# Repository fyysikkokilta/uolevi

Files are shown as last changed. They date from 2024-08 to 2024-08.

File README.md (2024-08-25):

# Uolevi

How to use Uolevi:
1. To PLAY a song, you can press the reset button in Uolevi's arm.
2. To STOP a song, you can hold the mode switch closer to the shoulder of the same arm until the eye LEDs turn on.
3. To CHANGE the song, you can keep holding the mode switch until the LEDs turn off, after which the number of beeps will indicate which song is selected. To select the next song, you can repeat this process. If the song selection is not indicated, you can retry changing the song, or reset Uolevi and retry. When you hear the correct number of beeps, you need to wait until the song is copied onto onboard memory and Uolevi plays the song. The eye LEDs indicate a loading is in progress. At most the loading time is approximately 6 minutes for the longest duration of song programmable (9 min 21 s).
4. To ADD new songs, you can take out the micro SD card in Uolevi's back, to the left of the battery compartment, and follow the programming instructions in the "Programming" directory.
---

Project documentation is split into the following directory structure:
- 3D Models: 3D-printable mechanical components
- Electronics: Schematics and bill of materials for PCB design
- Firmware: Code for microcontroller firmware
- Programming: Software and instructions for programming new songs onto Uolevi

Estimated current draw of Uolevi Rev 1.1 for functionalities and modes of operation at 4.5 V:
- Mouth motor: 0.9 A
- Legs motor: 0.4 A
- Eye LEDs: 2 x 20 mA
- Speaker: 40 mA
- Loading song from SD card onto external flash: 40 mA
- Standby mode (software power off): 4 mA
- Power off (timer chip 3.3 V cutoff): 50 nA

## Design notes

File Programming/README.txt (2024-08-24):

To program a song to Uolevi, open the "Songs" directory and create a file called "<song_name>.txt". Copy the .wav song file to be programmed to the same directory.

Different programming parameters are separated by lines, and data values are separated by spaces. The first line should contain the song file name. The next 4 lines should contain toggle times in seconds for the leg motor, mouth motor, left eye LED, and right eye LED, respectively.

Run the programmer.py script in the "Python" directory and input the "<song_name>.txt" file name for programming. Finally copy the created "<song_name>.ulv" to the root directory of the SD card and rename to indicate order ("<0-9>.ulv") in songs to load to Uolevi.
A song is loaded into active memory by inserting the SD card into Uolevi and holding Uolevi's upper left hand button down until the eye LEDs have turned on and off. This can be repeated to select the desired song, indicated by the number of beeps (1-10). Wait until the song starts playing to make sure loading is finished.

Below is an example of a programming file.
---
example.wav
0.0 1.0 5.0 5.1
0.01 0.012 0.053 0.1 2.0 2.1

1.0 4.8 5.25

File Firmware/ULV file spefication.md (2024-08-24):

# ULV File specification

ULV 1.0
- The ULV 1.0 file specification begins with a 4-byte header consisting of a 32-bit unsigned integer N, encoded as little endian. The header is then followed by N data bytes.
- The first data byte contains the first 2 "mechanical" samples with the following bit assignment: 0 (LSB) - leg motors 1st sample, 1 - mouth motor 1st sample, 2 - left eye LED 1st sample, 3 - right eye LED 1st sample, 4 - leg 2nd sample, 5 - mouth 2nd sample, 6 - left eye 2nd sample, 7 (MSB) - right eye 2nd sample.
- The next 1492 data bytes contain the first 1492 audio samples encoded as 8-bit unsigned integers. These are then followed by the next mechanical sample byte and the next 1492 data bytes, and so on, until the end of the file.

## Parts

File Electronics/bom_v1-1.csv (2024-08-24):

Reference | Value | Footprint | Qty
C1 | 100u | C_Radial_D5.0mm_H11.0mm_P2.00mm | 1
C2,C4,C7 | 1u | C_0603 | 3
C3,C6,C8,C9,C10 | 0.1u | C_0603 | 5
C5 | 0.47u | C_0603 | 1
D4 | 1N5822 | D_DO-201AD_P15.24mm_Horizontal | 1
J1 | MSD-1-A | MSD-1-A | 1
J8 | Header_UPDI | PinHeader_2x03_P2.54mm_Vertical | 1
Q1,Q2 | D882 | SOT-89-3 | 2
Q3 | BC856 | SOT-23-3 | 1
R1,R3 | 20k | R_0603 | 2
R2,R4 | 49.9 | R_0603 | 2
R5,R6,R9 | 200 | R_0603 | 3
R7 | 1M | R_0603 | 1
R8,R10 | 100k | R_0603 | 2
R11 | 47k | R_0603 | 1
U1 | ATtiny1614-SS | 14-SOIC | 1
U2 | W25Q128JVS | 8-SOIC | 1
U3 | MIC5504-3.3YM5 | SOT-23-5 | 1
U4 | TPL5110DDCTQ1 | SOT-23-6 | 1
U5 | IS31AP4991-SLS2 | 8-MSOP | 1

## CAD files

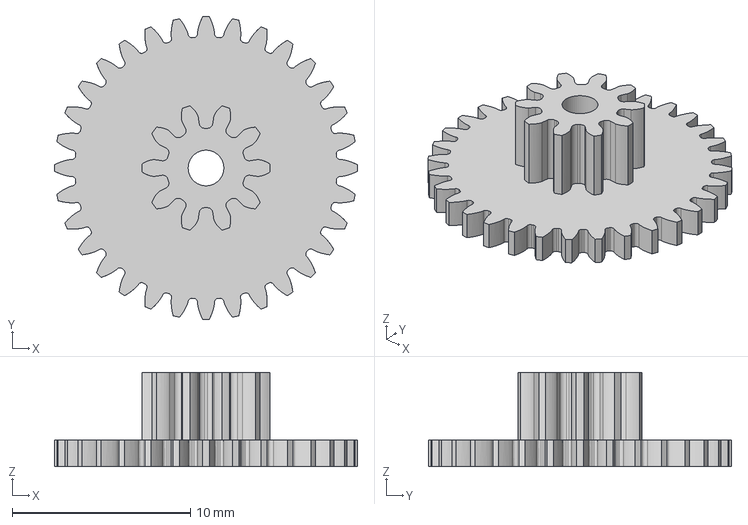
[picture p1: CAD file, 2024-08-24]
3D Models/gear_0_v1.step
17.0 x 17.0 x 5.30 mm
Spur Gear (32 teeth) (2)
Spur Gear (10 teeth)

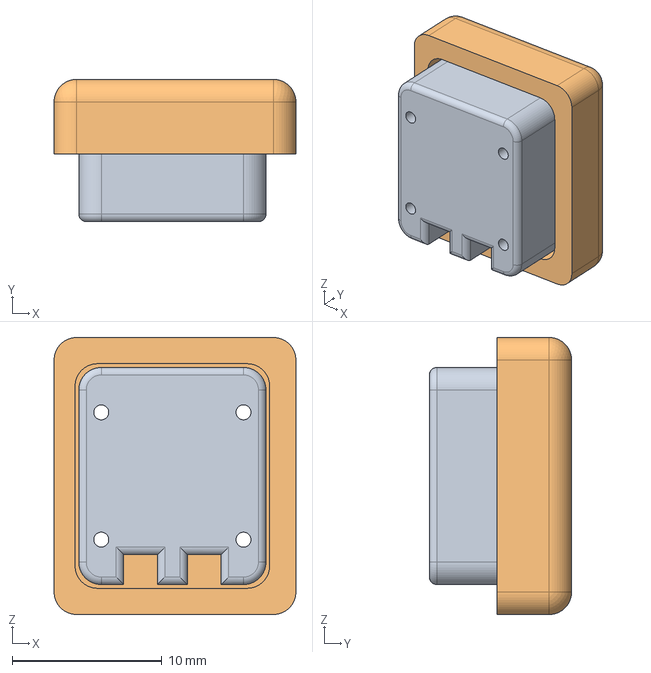
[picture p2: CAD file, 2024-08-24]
3D Models/switch_case_v1.step
16.1 x 9.50 x 18.5 mm

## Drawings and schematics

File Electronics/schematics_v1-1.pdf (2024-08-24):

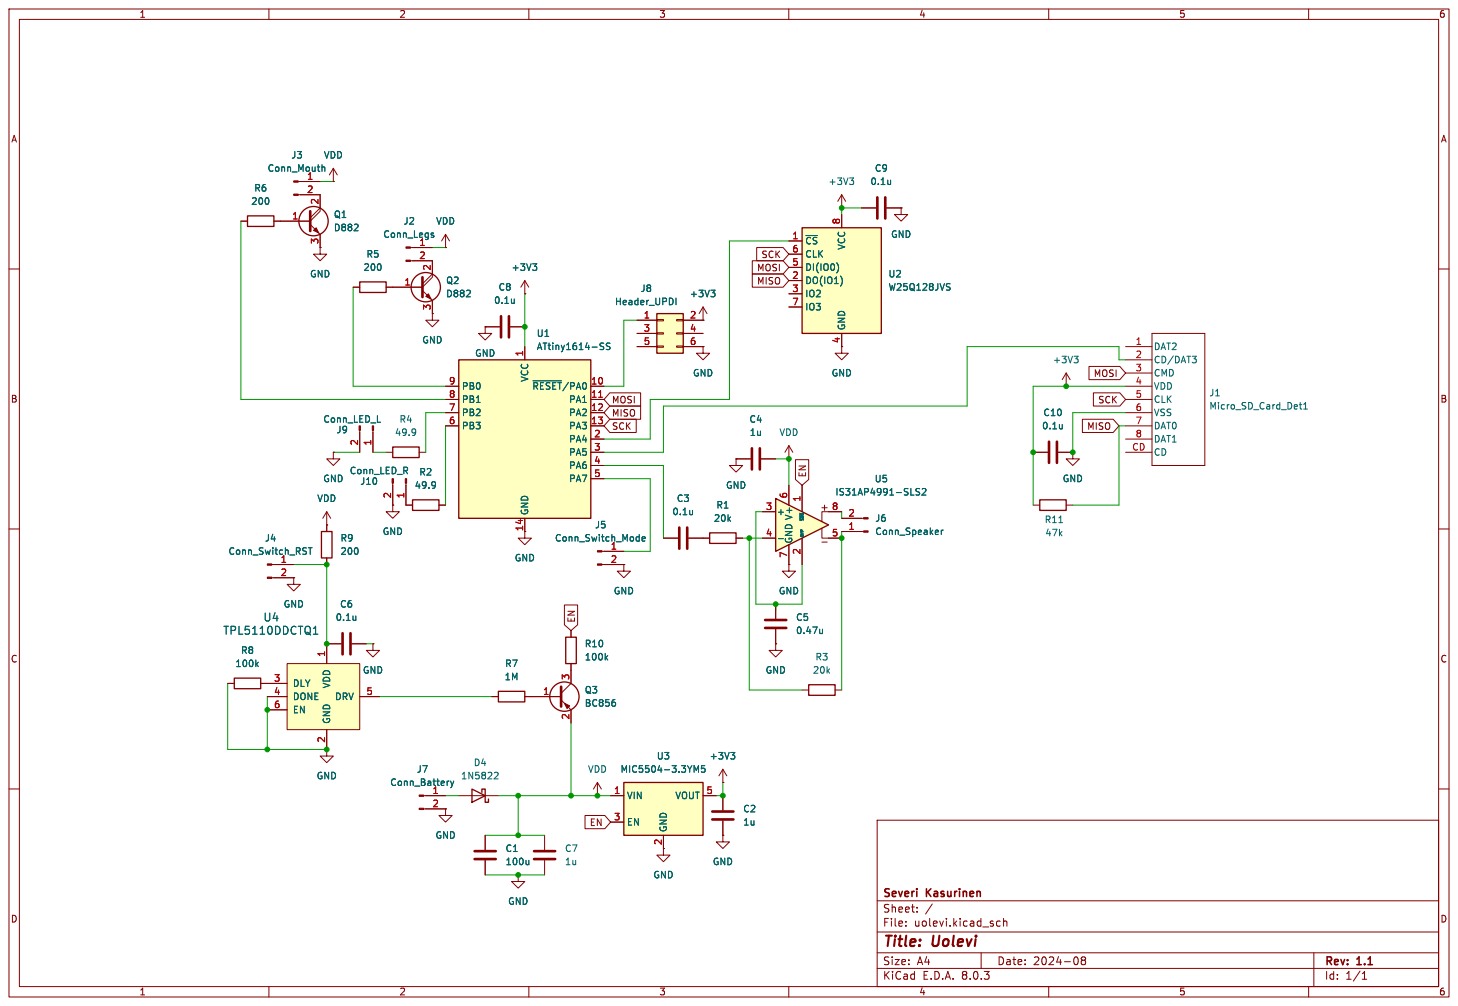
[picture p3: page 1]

1 ~{RESET}/PA010 PA1 11 PA2 12 PA3 13 GND 14 PA4 2 PA5 3 PA6 4 PA7 5 PB3 6 PB2 7 PB1 8 PB0 9 GND GND GND

1 ~{RESET}/PA010 PA1 11 PA2 12 PA3 13 GND 14 PA4 2 PA5 3 PA6 4 PA7 5 PB3 6 PB2 7 PB1 8 PB0 9 U1ATtiny1614-SS GND

2 EN 3 VOUT 5 U3 MIC5504-3.3YM5 GND GND GND

2 DLY 3 DONE 4 DRV 5 EN 6 U4 TPL5110DDCTQ1 C3

2 DLY 3 DONE 4 DRV 5 EN 6 C6

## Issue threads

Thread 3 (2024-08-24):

Electronics performance improvements

severikasurinen, 2024-08-24:
- Upgrade external flash module to e.g. W25Q512JVxIM/IQ for storing longer songs with higher sample rates or implementing permanent storage of certain songs
- Upgrade microcontroller to e.g. STM32C031G4U6 for shorter loading times with higher SPI data rates

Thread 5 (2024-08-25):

Implement BOD

severikasurinen, 2024-08-25:
Implement brown-out detection to avoid glitchy behavior when powered on with insufficient battery voltage.

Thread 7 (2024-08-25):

ULV 2.0 file specification

severikasurinen, 2024-08-25:
The ULV 1.0 file specification lacks in future-proofing, and should be replaced by a new (incompatible) file specification (2.0) with some extra bytes before sample data for possible configuration data, such as audio/mechanical sample rate or bit depth information, also enabling PWM and other functionality to be added later on. This could be implemented by e.g. reserving the first cluster for configuration data and starting the song read from the first byte of the second data cluster.

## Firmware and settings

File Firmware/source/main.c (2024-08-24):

#include <stdlib.h>
#include <avr/cpufunc.h>
#include <avr/io.h>
#include <avr/interrupt.h>
#include <string.h>
#include <avr/sleep.h>
#include "petitfs/diskio.h"
#include "petitfs/pff.h"

#include "main.h"
#include "gpio.h"
#include "spi.h"
#include "flash.h"

#define BUFFER_SIZE 1024

FATFS file_system;
uint8_t reset = 0;
uint8_t sd_initialized = 0;
uint8_t file_num = 0;

// Initialize main and Timer A clocks

uint8_t clk_init(void) {
    while (!(CLKCTRL.MCLKSTATUS & (1 << 4)));
    *((volatile unsigned char*) (0x0030 + 0x04)) = 0xD8; // Unlock IOREG
    CLKCTRL.MCLKCTRLB = 1; // Set CPU clock to 10 MHz

    // Start Timer A clock at 39.0625 kHz
    TCA0.SINGLE.PER = 0xFFFF;
    TCA0.SINGLE.CTRLA = (0x6 << 1) | 1;

    return 0;
}

// Disable peripherals and power down

void shutdown(void) {
    disable_sd_card();
    spi_shutdown(); // Disable SPI

    DAC0.CTRLA = 0; // Disable DAC

    // Clear GPIO
    PORTA.OUTCLR = 0xFF;
    PORTA.DIRSET = 0;
    PORTB.OUTCLR = 0xFF;
    PORTB.DIRSET = 0;

    SLPCTRL.CTRLA = (0x2 << 1) | 1; // Set sleep mode to power down
    sleep_mode(); // Sleep
}

// Wait for Timer A clocks (25.6 us per clock)

uint8_t delay_clks(uint8_t delay) {
    uint16_t end_val = TCA0.SINGLE.CNT + delay;

    if (end_val < TCA0.SINGLE.CNT) {
        while (!(TCA0.SINGLE.INTFLAGS & 1));
        TCA0.SINGLE.INTFLAGS |= 1;
    }

    while (TCA0.SINGLE.CNT < end_val);

    return 0;
}

// Wait for milliseconds (max. 1680)

uint8_t delay_ms(uint16_t delay) {
    uint16_t end_val = TCA0.SINGLE.CNT + delay * 39;

    if (end_val < TCA0.SINGLE.CNT) {
        while (!(TCA0.SINGLE.INTFLAGS & 1));
        TCA0.SINGLE.INTFLAGS |= 1;
    }

    while (TCA0.SINGLE.CNT < end_val);

    return 0;
}

// Beep for given number of times

void beep(uint8_t beeps) {
    for (uint8_t i = 0; i < beeps; i++) {
        for (uint8_t j = 0; j < 244; j++) {
            dac_write(0);
            delay_clks(32);
            dac_write(0x0F);
            delay_clks(32);
        }
        delay_ms(800);
    }
}

// Initialize microSD card in SPI mode and mount file system

uint8_t init_sd_card(void) {
    spi_peripheral(0, 0);

    FRESULT result;
    DSTATUS status = STA_NOINIT;

    uint8_t spi_presc = (SPI0.CTRLA >> 1) & 0x3;
    SPI0.CTRLA = SPI0.CTRLA & ~(0x3 << 1);
    SPI0.CTRLA |= (0x2 << 1); // Set SPI freq. to 312.5 kHz

    /* Initialize physical drive */
    status = disk_initialize();
    if (status == STA_NODISK) {
        return 1;
    }

    SPI0.CTRLA = SPI0.CTRLA & ~(0x3 << 1);
    SPI0.CTRLA |= (spi_presc << 1); // Reset SPI freq. setting

    /* Mount volume */
    result = pf_mount(&file_system);
    if (result != FR_OK) {
        return 2;
    }

    sd_initialized = 1;

    return 0;
}

uint8_t disable_sd_card(void) {
    if (sd_initialized) {
        spi_peripheral(0, 0);
        disk_idle(&file_system);
        sd_initialized = 0;
    }

    return 0;
}

// Try opening file from microSD card

uint8_t open_file(uint8_t f_num) {
    if (f_num > 10)
        return 1;

    if (!sd_initialized) {
        init_sd_card();
    }

    // Give empty clocks for SD card
    spi_peripheral(0, 0);
    spi_peripheral(1, 0);
    for (int i = 0; i < 8; i++) {
        spi_transfer(0xFF);
    }

    FRESULT result;
    char filename[6] = {'0' + (f_num - 1), '.', 'U', 'L', 'V', '\0'};
    result = pf_open(filename);
    if (result != FR_OK) {
        return 2;
    }

    sd_initialized = 2;

    return 0;
}

// Transfer opened file from microSD card to external flash memory

uint8_t read_file(void) {
    spi_peripheral(0, 0);

    if (sd_initialized != 2 && open_file(file_num)) {
        return 1;
    }
    beep(file_num);
    delay_ms(1200);

    gpio_write(1, 2, 0);
    gpio_write(1, 3, 1);

    uint16_t rx_bytes;
    uint8_t rx_buff[BUFFER_SIZE];
    uint8_t highest_byte;

    uint16_t erases = 0;
    uint16_t flash_address = 0;
    uint8_t flash_i = 0;
    while (1) {
        if (reset) {
            spi_peripheral(0, 0);
            return 2;
        }

        pf_read(rx_buff, BUFFER_SIZE, &rx_bytes);


        if (!erases) {
            highest_byte = rx_buff[3];
            uint32_t bytes = 0;
            for (uint8_t i = 0; i < 4; i++) {
                bytes |= (uint32_t) rx_buff[i] << (8 * i);
            }
            bytes += 4;

            erases = (bytes >> 16);
            if (bytes & 0xFFFF) {
                erases++;
            }

            rx_buff[3] = 0xFF; // Erase highest byte count byte until finished

            for (uint16_t i = 0; i < erases; i++) {
                if (reset) {
                    spi_peripheral(0, 0);
                    return 2;
                }

                PORTB.OUTTGL = 1 << 2;
                // Erase 64kB block
                flash_write_enable(); // Enable writing
                spi_peripheral(0, 1);
                spi_transfer(0xD8);
                spi_transfer(i);
                spi_transfer(0x00);
                spi_transfer(0x00);
                spi_peripheral(0, 0);

                // Wait for erase
                flash_wait();
            }
            gpio_write(1, 2, 0);
            gpio_write(1, 3, 1);
        }

        PORTB.OUTTGL = 1 << 3 | 1 << 2;
        flash_i = 0;
        for (uint16_t i = 0; i < rx_bytes; i++) {
            if (reset) {
                spi_peripheral(0, 0);
                return 2;
            }

            if (!flash_i) {

                spi_peripheral(0, 0);

                // Wait until not busy
                flash_wait();

                // Write
                flash_write_enable(); // Enable writing
                spi_peripheral(0, 1);
                spi_transfer(0x02);
                spi_transfer((flash_address >> 8) & 0xFF);
                spi_transfer(flash_address & 0xFF);
                spi_transfer(0x00);

                flash_address++;
            }
            spi_transfer(rx_buff[i]);
            flash_i++;
        }
        spi_peripheral(0, 0);

        if (rx_bytes != BUFFER_SIZE) {
            break;
        }
    }
    // Wait until not busy
    flash_wait();

    // Write first byte to indicate finished read
    flash_write_enable(); // Enable writing

    spi_peripheral(0, 1);
    spi_transfer(0x02);
    spi_transfer(0x00);
    spi_transfer(0x00);
    spi_transfer(0x03);
    spi_transfer(highest_byte);
    spi_peripheral(0, 0);

    gpio_write(1, 3, 0);

    disable_sd_card();

    return 0;
}

// Play song from external flash memory

uint8_t play(void) {
    // Wait until not busy
    flash_wait();

    // Start read
    spi_peripheral(0, 1);
    spi_transfer(0x03);
    spi_transfer(0x00);
    spi_transfer(0x00);
    spi_transfer(0x00);

    // Read number of data bytes
    uint32_t bytes = 0;
    for (int i = 0; i < 4; i++) {
        bytes |= (uint32_t) spi_transfer(0xFF) << (8 * i);
    }

    if (!(bytes >> 24)) {
        uint8_t mech_byte = 0;
        uint16_t j = 0;
        for (uint32_t i = 0; i < bytes; i++) {
            if (reset)
                return 1;

            if (j == 0) { // Play next mech sample
                if (!mech_byte) {
                    mech_byte = spi_transfer(0xFF); // Read next byte
                    i++;

                    // Play mech sample
                    gpio_write(1, 0, mech_byte & 1);
                    gpio_write(1, 1, mech_byte & (1 << 1));
                    gpio_write(1, 2, mech_byte & (1 << 2));
                    gpio_write(1, 3, mech_byte & (1 << 3));

                    mech_byte = mech_byte | 1;

                    for (uint8_t k = 0; k < 6; k++)
                        __asm__ __volatile__("nop "); // Adjust timing

                    __asm__ __volatile__("nop "); // Adjust timing
                    __asm__ __volatile__("nop "); // Adjust timing
                    __asm__ __volatile__("nop "); // Adjust timing
                } else {
                    gpio_write(1, 0, mech_byte & (1 << 4));
                    gpio_write(1, 1, mech_byte & (1 << 5));
                    gpio_write(1, 2, mech_byte & (1 << 6));
                    gpio_write(1, 3, mech_byte & (1 << 7));

                    mech_byte = 0;

                    for (uint8_t k = 0; k < 20; k++)
                        __asm__ __volatile__("nop "); // Adjust timing

                    __asm__ __volatile__("nop "); // Adjust timing
                    __asm__ __volatile__("nop "); // Adjust timing
                    __asm__ __volatile__("nop "); // Adjust timing
                }
                j = 746;
            } else {
                for (uint8_t k = 0; k < 62; k++)
                    __asm__ __volatile__("nop "); // Adjust timing

                __asm__ __volatile__("nop "); // Adjust timing
                __asm__ __volatile__("nop "); // Adjust timing
                __asm__ __volatile__("nop "); // Adjust timing
            }
            j--;
            dac_write(spi_transfer(0xFF)); // Play next audio sample
        }
    } else {
        spi_peripheral(0, 0);
        return 1;
    }
    spi_peripheral(0, 0);
    return 0;
}

// Mode button interrupt

ISR(PORTA_PORT_vect) {
    PORTA.INTFLAGS |= 1 << 7;

    gpio_write(1, 0, 0);
    gpio_write(1, 1, 0);
    gpio_write(1, 2, 0);
    gpio_write(1, 3, 0);

    uint8_t wait_time = 0;
    while (!(PORTA.IN & (1 << 7)) && wait_time < 50) {
        delay_ms(10);
        wait_time++;

        if (wait_time >= 50) {
            break;
        }
    }
    if (wait_time < 50)
        return;

    gpio_write(1, 2, 1);
    gpio_write(1, 3, 1);

    wait_time = 0;
    while (!(PORTA.IN & (1 << 7))) {
        delay_ms(10);
        wait_time++;

        if (wait_time >= 150) {
            gpio_write(1, 2, 0);
            gpio_write(1, 3, 0);
            while (!(PORTA.IN & (1 << 7)));
            break;
        }
    }
    if (wait_time < 150) {
        cli(); // Block interrupts
        shutdown();
        sei(); // Unblock interrupts
    }

    file_num++;
    if (file_num != 1 && open_file(file_num)) {
        file_num = 1;
    }

    if (!open_file(file_num)) {
        reset = 1;
    }
}

// Loop function

uint8_t loop(void) {
    if (!reset && play()) {
        if (!reset) {
            file_num = 1;
            if (!read_file()) {
                play();
            }
        }
    }
    if (reset) {
        reset = 0;
        read_file();
        return 1;
    }

    return 0;
}

// Enter function

int main(void) {
    cli(); // Block interrupts
    clk_init();
    gpio_init();
    
    // Slowly move DAC to center value
    for(uint8_t i = 0; i < 128; i++) {
        dac_write(0xFF - i);
        delay_clks(1);
    }
    
    spi_init();
    sei(); // Unblock interrupts
    
    while (loop());
    shutdown();

    return 0;
}

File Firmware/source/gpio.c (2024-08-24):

#include <avr/io.h>

#include "gpio.h"


uint8_t gpio_write(uint8_t port, uint8_t pin, uint8_t value) {
    if (port == 0) {
        if(value) {
            PORTA.OUTSET = (1 << pin);
        }
        else {
            PORTA.OUTCLR = (1 << pin);
        }
    }
    else if (port == 1) {
        if(value) {
            PORTB.OUTSET = (1 << pin);
        }
        else {
            PORTB.OUTCLR = (1 << pin);
        }
    }
    else {
        return 1;
    }
    return 0;
}

void dac_write(uint8_t value) {
    DAC0.DATA = value;
}

void dac_enable(uint8_t en) {
    DAC0.CTRLA = (DAC0.CTRLA & ~(1 << 6)) | (en << 6);
}

void gpio_init(void) {
    PORTA.DIRSET = (1 << 5) | (1 << 4) | (1 << 3) | (1 << 1);
    PORTB.DIRSET = (1 << 3) | (1 << 2) | (1 << 1) | 1;
    
    //PORTA.PIN2CTRL = (1 << 3);    // Enable MISO pull-up resistor
    PORTA.PIN7CTRL = (1 << 3) | 0x3;    // Enable mode switch pull-up resistor and falling-edge interrupt
    
    CPUINT.STATUS |= 1 << 7;
    
    VREF.CTRLA |= 0x4;
    
    DAC0.DATA = 0xFF;
    DAC0.CTRLA |= 1;
    dac_enable(1);
}

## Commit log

2024-08-24 Initial commit
    Uploaded existing files to repository
    [bom_v1-1.csv, gear_0_v1.step, switch_case_v1.step]
2024-08-24 Update README
    Added current draw information
